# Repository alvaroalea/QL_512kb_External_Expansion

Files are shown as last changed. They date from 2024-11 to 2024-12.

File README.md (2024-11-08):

# SINCLAIR QL 512kB External Rom Expansion

(C) 2022 Alvaro Alea Fernandez

License under: CERN Open Hardware Licence Version 2 - Strongly Reciprocal

https://ohwr.org/cern_ohl_s_v2.txt

This is based on the work of McLeod Ideafix, Jose Leandro, Zerover and tcat between others. 

This board will provide up to 512kB aditional of static RAM (fast-ram) to the sinclair QL.

Two board can be stacked to got a maximun of 898Kb of Memory. (same as Miracle's Trump Card)

Be aware you can not have 2 memory expansion in same area (Jose Leandro's QBide, Trump Card, etc...)

Provide a expansion conector to allow conect aditional interfaces.

There area available 4 configuration trough solder jumpers in the PCB.
* 512kB - This is the standar 512kB expansion for any QL
* 256kB - This is for use as a second expansion, use the full QL space for a maximun of 898kB, be aware that this is incompatible with a lot of expansion card, so use with caution (Any expansion card that do not use jumper for configuration will be incompatible).
* 192kB - Similar to 256kB provide aditional space for expansion cards correctly configured.
* 128kB - Similar to 256kB provide aditional space for expansion cards correctly configured.

Be aware that the configuration of 128Kb can not be installed alone.
For be able to use 128kB, for a total of 768kB, is mandatory to have an aditional expansion card that put ROM in address E00000h, in other case the QL ROM will hang indicating RAM malfunction, because a weired overlap of the internal 128kB with this external 128kB.

https://www.instagram.com/p/CZWfWcUM5mx/

In the GAL folder there is the source code to be compiled with GALasm that you can found here: https://github.com/daveho/GALasm

## Mini Trump Card Compatibility

I have done a version of the trump card disk interface here: https://github.com/alvaroalea/QL_MiniTrump3 , this interface do not
provide memory like the original one. You can combine two of this card and the minitrump to got the same of the original trump card.

You should conect the 512Kb Card to the QL, the MiniTrump Card to the 512Kb, and the +256Kb card to the Mini Trump, and in this board
yo need to change the solder jumper (JP1) to 2-3 to allow the Minitrump card to coordinate with the second memory card.

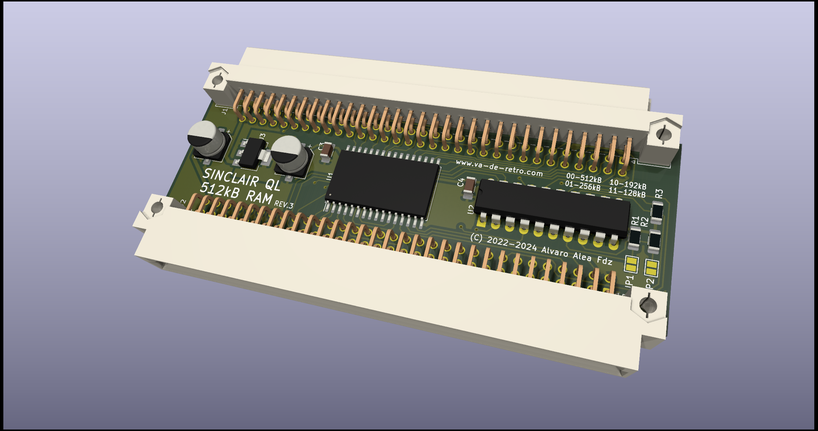
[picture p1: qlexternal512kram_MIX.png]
My image


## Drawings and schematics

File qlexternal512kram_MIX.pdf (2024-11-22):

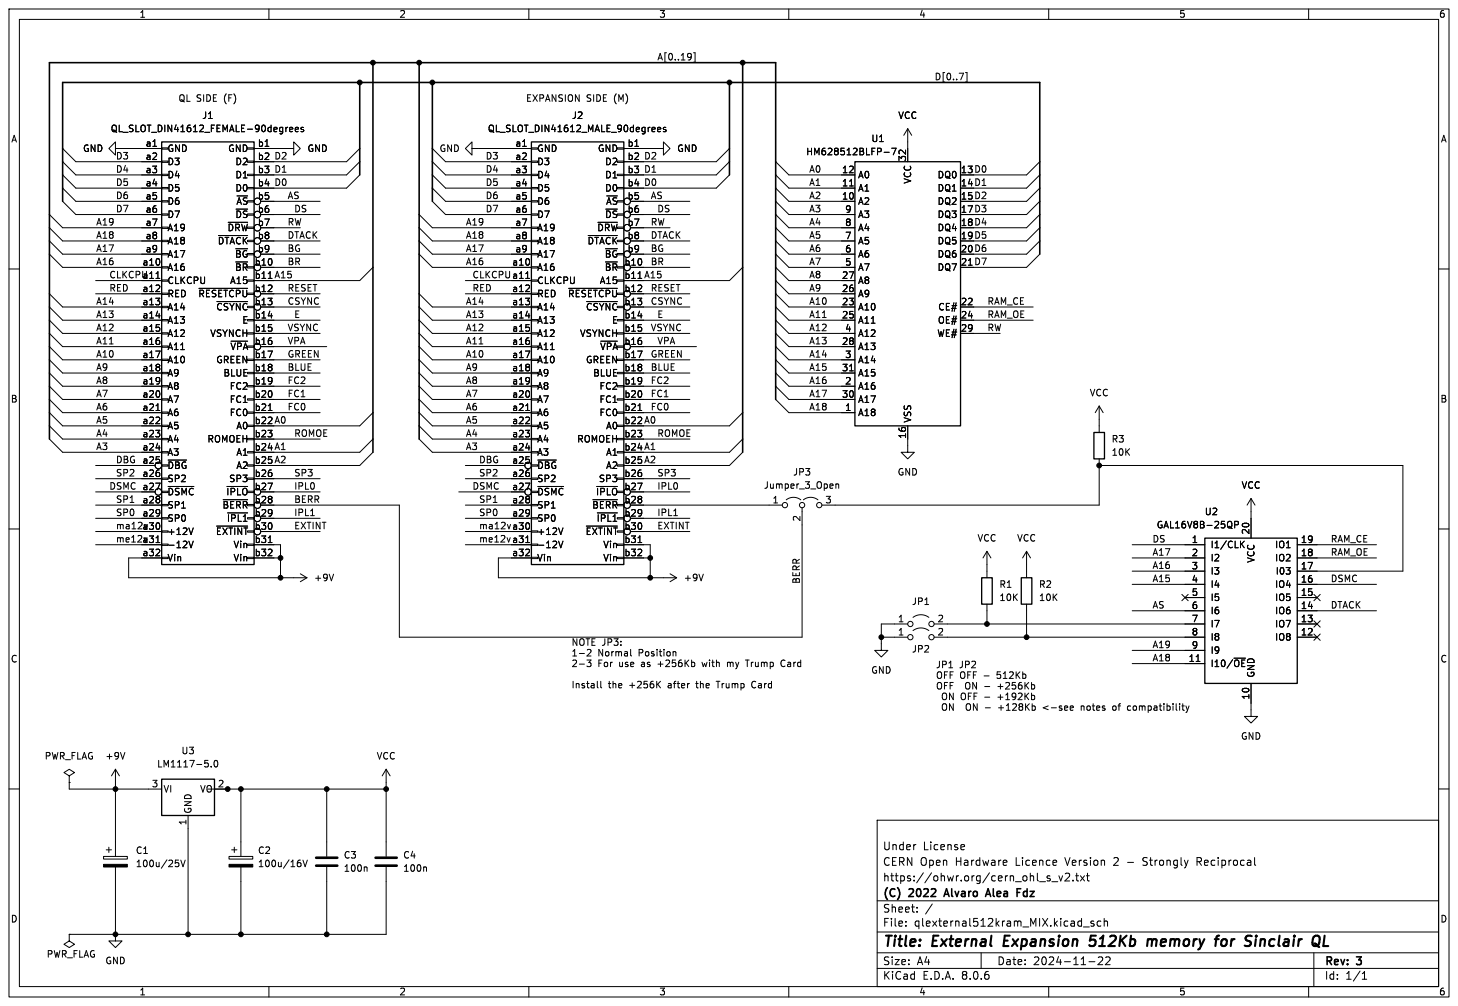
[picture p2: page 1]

J1 QL_SLOT_DIN41612_FEMALE-90degrees GND a1 A16 a10 CLKCPU a11 RED a12 A14 a13 A13 a14 A12 a15 A11 a16 A10 a17 A9 a18 A8 a19 D3 a2 A7 a20 A6 a21 A5 a22 A4 a23 A3 a24 ~{DBG} a25 SP2 a26 ~{DSMC} a27 SP1 a28 SP0 a29 D4 a3 +12V a30
b14 VSYNCH b15 ~{VPA}b16 GREEN b17 BLUE b18 FC2 b19 D2 b2 FC1 b20 FC0 b21 A0 b22 ROMOEH b23 A1 b24 A2 b25 SP3 b26 ~{IPLO}b27 ~{BERR}b28 ~{IPL1}b29 D1 b3 ~{EXTINT}b30 Vin b31 Vin b32 D0 b4 ~{AS}b5 ~{DS}b6 ~{DRW}b7 ~{DTACK}b8 ~{BG}b9
ASCSYNC

VCC GND a1 A16 a10 CLKCPU a11 RED a12 A14 a13 A13 a14 A12 a15 A11 a16 A10 a17 A9 a18 A8 a19 D3 a2 A7 a20 A6 a21 A5 a22 A4 a23 A3 a24 ~{DBG} a25 SP2 a26 ~{DSMC} a27 SP1 a28 SP0 a29 D4 a3 +12V a30

Id: 1/1 Title: External Expansion 512Kb memory for Sinclair QL

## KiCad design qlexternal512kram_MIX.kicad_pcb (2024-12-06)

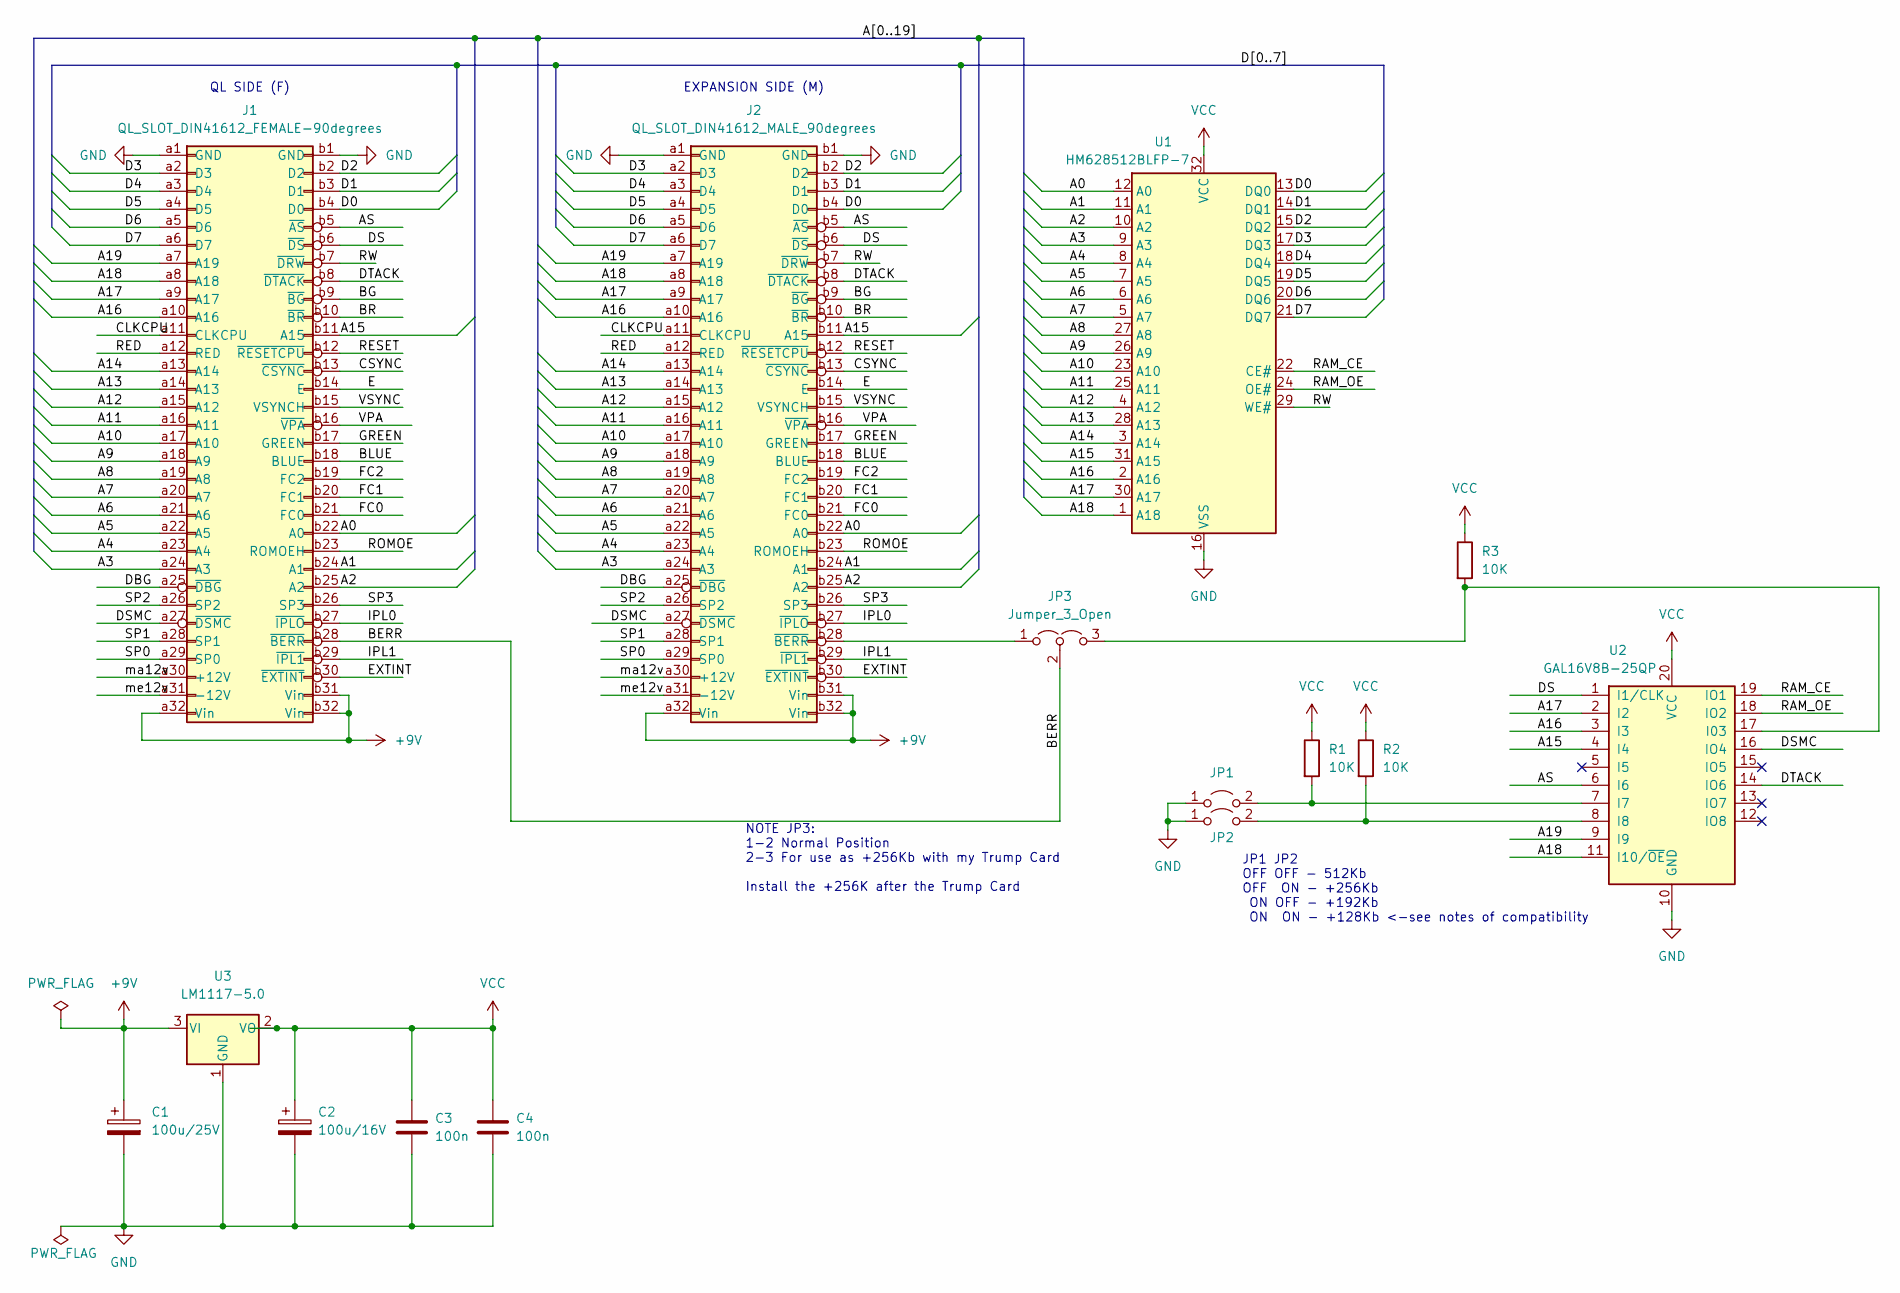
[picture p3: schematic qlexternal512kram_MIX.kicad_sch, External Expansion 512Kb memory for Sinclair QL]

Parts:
C1: 100u/25V; CP_Elec_6.3x5.4
C2: 100u/16V; CP_Elec_6.3x5.4
C3, C4: 100n; C_1206_3216Metric_Pad1.33x1.80mm_HandSolder
J1: QL_SLOT_DIN41612_FEMALE-90degrees; DIN41612_B_2x32_Female_Horizontal_THT
J2: QL_SLOT_DIN41612_MALE_90degrees; DIN41612_B_2x32_Male_Horizontal_THT
JP1, JP2: Jumper_2_Open; SolderJumper-2_P1.3mm_Open_Pad1.0x1.5mm
JP3: Jumper_3_Open; SolderJumper-3_P1.3mm_Open_Pad1.0x1.5mm
R1, R2, R3: 10K; R_1206_3216Metric_Pad1.30x1.75mm_HandSolder
U1: HM628512BLFP-7; SSOP-32_11.305x20.495mm_P1.27mm
U2: GAL16V8B-25QP; DIP-20_W7.62mm_LongPads
U3: LM1117-5.0; SOT-223-3_TabPin2

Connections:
+9V: C1.1, J1.a32 (Vin), J1.b31 (Vin), J1.b32 (Vin), J2.a32 (Vin), J2.b31 (Vin), J2.b32 (Vin), U3.3 (VI)
/A0: J1.b22 (A0), J2.b22 (A0), U1.12 (A0)
/A1: J1.b24 (A1), J2.b24 (A1), U1.11 (A1)
/A2: J1.b25 (A2), J2.b25 (A2), U1.10 (A2)
/A3: J1.a24 (A3), J2.a24 (A3), U1.9 (A3)
/A4: J1.a23 (A4), J2.a23 (A4), U1.8 (A4)
/A5: J1.a22 (A5), J2.a22 (A5), U1.7 (A5)
/A6: J1.a21 (A6), J2.a21 (A6), U1.6 (A6)
/A7: J1.a20 (A7), J2.a20 (A7), U1.5 (A7)
/A8: J1.a19 (A8), J2.a19 (A8), U1.27 (A8)
/A9: J1.a18 (A9), J2.a18 (A9), U1.26 (A9)
/A10: J1.a17 (A10), J2.a17 (A10), U1.23 (A10)
/A11: J1.a16 (A11), J2.a16 (A11), U1.25 (A11)
/A12: J1.a15 (A12), J2.a15 (A12), U1.4 (A12)
/A13: J1.a14 (A13), J2.a14 (A13), U1.28 (A13)
/A14: J1.a13 (A14), J2.a13 (A14), U1.3 (A14)
/A15: J1.b11 (A15), J2.b11 (A15), U1.31 (A15), U2.4 (I4)
/A16: J1.a10 (A16), J2.a10 (A16), U1.2 (A16), U2.3 (I3)
/A17: J1.a9 (A17), J2.a9 (A17), U1.30 (A17), U2.2 (I2)
/A18: J1.a8 (A18), J2.a8 (A18), U1.1 (A18), U2.11 (I10/~OE)
/A19: J1.a7 (A19), J2.a7 (A19), U2.9 (I9)
/AS: J1.b5 (~AS), J2.b5 (~AS), U2.6 (I6)
/BERR: J1.b28 (~BERR), JP3.2 (C)
/BG: J1.b9 (~BG), J2.b9 (~BG)
/BLUE: J1.b18 (BLUE), J2.b18 (BLUE)
/BR: J1.b10 (~BR), J2.b10 (~BR)
/CLKCPU: J1.a11 (CLKCPU), J2.a11 (CLKCPU)
/CSYNC: J1.b13 (~CSYNC), J2.b13 (~CSYNC)
/D0: J1.b4 (D0), J2.b4 (D0), U1.13 (DQ0)
/D1: J1.b3 (D1), J2.b3 (D1), U1.14 (DQ1)
/D2: J1.b2 (D2), J2.b2 (D2), U1.15 (DQ2)
/D3: J1.a2 (D3), J2.a2 (D3), U1.17 (DQ3)
/D4: J1.a3 (D4), J2.a3 (D4), U1.18 (DQ4)
/D5: J1.a4 (D5), J2.a4 (D5), U1.19 (DQ5)
/D6: J1.a5 (D6), J2.a5 (D6), U1.20 (DQ6)
/D7: J1.a6 (D7), J2.a6 (D7), U1.21 (DQ7)
/DBG: J1.a25 (~DBG), J2.a25 (~DBG)
/DS: J1.b6 (~DS), J2.b6 (~DS), U2.1 (I1/CLK)
/DSMC: J1.a27 (~DSMC), J2.a27 (~DSMC), U2.16 (IO4)
/DTACK: J1.b8 (~DTACK), J2.b8 (~DTACK), U2.14 (IO6)
/E: J1.b14 (E), J2.b14 (E)
/EXTINT: J1.b30 (~EXTINT), J2.b30 (~EXTINT)
/FC0: J1.b21 (FC0), J2.b21 (FC0)
/FC1: J1.b20 (FC1), J2.b20 (FC1)
/FC2: J1.b19 (FC2), J2.b19 (FC2)
/GREEN: J1.b17 (GREEN), J2.b17 (GREEN)
/IPL0: J1.b27 (~IPLO), J2.b27 (~IPLO)
/IPL1: J1.b29 (~IPL1), J2.b29 (~IPL1)
/RAM_CE: U1.22 (CE#), U2.19 (IO1)
/RAM_OE: U1.24 (OE#), U2.18 (IO2)
/RED: J1.a12 (RED), J2.a12 (RED)
/RESET: J1.b12 (~RESETCPU), J2.b12 (~RESETCPU)
/ROMOE: J1.b23 (ROMOEH), J2.b23 (ROMOEH)
/RW: J1.b7 (~DRW), J2.b7 (~DRW), U1.29 (WE#)
/SP0: J1.a29 (SP0), J2.a29 (SP0)
/SP1: J1.a28 (SP1), J2.a28 (SP1)
/SP2: J1.a26 (SP2), J2.a26 (SP2)
/SP3: J1.b26 (SP3), J2.b26 (SP3)
/VPA: J1.b16 (~VPA), J2.b16 (~VPA)
/VSYNC: J1.b15 (VSYNCH), J2.b15 (VSYNCH)
/ma12v: J1.a30 (+12V), J2.a30 (+12V)
/me12v: J1.a31 (-12V), J2.a31 (-12V)
GND: C1.2, C2.2, C3.2, C4.2, J1.a1 (GND), J1.b1 (GND), J2.a1 (GND), J2.b1 (GND), JP1.1 (A), JP2.1 (A), U1.16 (VSS), U2.10 (GND), U3.1 (GND)
unnamed: J2.b28 (~BERR), JP3.1 (A)
unnamed: JP1.2 (B), R1.2, U2.7 (I7)
unnamed: JP2.2 (B), R2.2, U2.8 (I8)
unnamed: JP3.3 (B), R3.2, U2.17 (I03)
VCC: C2.1, C3.1, C4.1, R1.1, R2.1, R3.1, U1.32 (VCC), U2.20 (VCC), U3.2 (VO)

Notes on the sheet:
NOTE JP3: 1-2 Normal Position 2-3 For use as +256Kb with my Trump Card Install the +256K after the Trump Card
EXPANSION SIDE (M)
JP1 JP2 OFF OFF - 512Kb OFF ON - +256Kb ON OFF - +192Kb ON ON - +128Kb <-see notes of compatibility
QL SIDE (F)

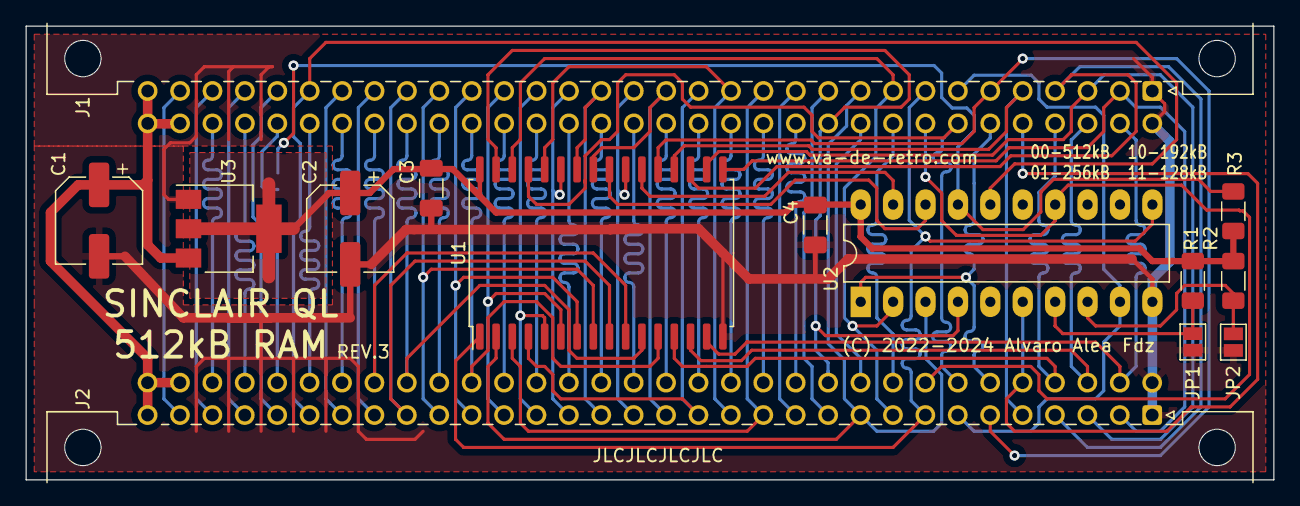
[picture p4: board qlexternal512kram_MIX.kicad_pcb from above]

Board: 2 copper layers, 97.8 x 35.6 mm, 15 parts (1 on the bottom side), 68 nets.

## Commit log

2022-02-14 Fix reference for IC
    [qlexternal512kram_MIX.kicad_pcb, qlexternal512kram_MIX.kicad_sch]
2022-07-15 Updated info
    [qlexternal512kram_MIX-B_Cu.gbr, qlexternal512kram_MIX-B_Mask.gbr, qlexternal512kram_MIX-B_Paste.gbr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]
2023-12-26 Update QL Conector
    [qlexternal512kram_MIX-B_Cu.gbr, qlexternal512kram_MIX-B_Mask.gbr, qlexternal512kram_MIX-B_Paste.gbr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]
2023-12-26 update gerber zip
2024-11-08 Add compatibility with MiniTrump Card, and moved GAL to galasm
    [qlexternal512kram_MIX-B_Cu.gbr, qlexternal512kram_MIX-B_Mask.gbr, qlexternal512kram_MIX-B_Silks.gbr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]
2024-11-22 minor typos
    [qlexternal512kram_MIX.kicad_pcb, qlexternal512kram_MIX.kicad_sch]
2024-12-06 typo in skillscreen
    [qlexternal512kram_MIX-B_Cu.gbr, qlexternal512kram_MIX-B_Mask.gbr, qlexternal512kram_MIX-B_Paste.gbp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]

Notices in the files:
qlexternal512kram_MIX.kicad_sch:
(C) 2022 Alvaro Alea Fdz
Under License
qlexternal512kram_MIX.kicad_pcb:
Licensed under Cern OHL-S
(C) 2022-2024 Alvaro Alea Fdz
